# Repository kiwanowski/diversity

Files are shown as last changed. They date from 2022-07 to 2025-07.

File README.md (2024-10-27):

# diversity
an affordable DIY and open source alternative to the M8 tracker

## Limitations
The official firmware needs to be patched to work with this device.

## Support

[Please support the original M8 tracker author](https://www.patreon.com/trash80)

I won't provide support for any boards or schematics other than the ones provided in the repository.

I do not take reponsibility for any damage done. Please be sure that you understand what you are doing.

Creative Commons cc-by-sa 4.0 license.

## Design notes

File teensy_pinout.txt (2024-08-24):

0
1 - midi out
2 - LCD DC
3 - LCD RESET
4 - SD detect
5 - MCP23008 INT
6 - LCD BACKLIGHT
7 - PCM5102a DIN
8 - PCM1808 DOUT
9 - INT touch
10 - LCD CS
11 - LCD MOSI
12 - LCD MISO

13 - LCD SCK
14 - battery charger CHRG
15 - battery charger POWER ON
16 - MCP23008 SCL
17 - MCP23008 SDA
18 - audio i2s
19 - audio i2s
20 - PCM5102a LCK
21 - PCM5102a BCK
22 - Battery level input
23 - PCM5102a SCK

24 - power button
25
26 - headphones detect
27
28 - midi in
29
30 - speakers control
31
32
33

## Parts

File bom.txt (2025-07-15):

M8 board:

Teensy micromod
U1, U2, U3, U4, U5, U6, U7, U8 - Kailh Choc low profile switch https://www.aliexpress.com/item/1005006626760418.html
U1, U2, U3, U4, U5, U6, U7, U8 - Kailh Choc low profile keycap https://www.aliexpress.com/item/1005005792485443.html
J8 - 3.2 inch ILI9341 IPS LCD https://www.aliexpress.com/item/1005007253437576.html
TP4056 charger module
PCM5102A DAC module https://www.aliexpress.com/item/4000397296348.html
CS5343 ADC https://www.aliexpress.com/item/1005006998764471.html
J9 - micro SD socket https://www.aliexpress.com/item/32802051702.html
IC3 - MCP23008-E/SO
Switch SKHHLUA010 https://pl.aliexpress.com/item/1005004288237245.html
IC1 - 6N138
J3, J4, J11, J13 - headphone jack https://www.aliexpress.com/item/32439357849.html
507070 3000mah battery
Usb-C socket https://pl.aliexpress.com/item/1005006257173539.html
Switch TS-1286VE-2 https://pl.aliexpress.com/item/1005002844865456.html
LT1963AES8-3.3
M.2 socket, E key H=4.2 https://pl.aliexpress.com/item/4001262336295.html

R1, R2 2k2 ohm 0805
R5 220 ohm 0805
R3, R6, R17, R18, R19, R20 33 ohm 0805
R7 10 ohm 0805
R8 470 ohm 0805
R9 1k ohm 0805
R12, R13, R14 100k ohm 0805
R21 10k ohm 0805
R4, R10, R11, R22, R23, R24 5k1 ohm 0805
C1, C2, C5 10uF 0805
C3, C4, C6, C8, C12, C13, C22 100nF 0805
C11, C14, C15, C16, C25 1uF 0805
C7, C17 180pF 0805
D3 1N4148 SMD

Case:

4x Threaded Insert M2.5 4mm https://www.aliexpress.com/item/1005004535859664.html
4x Screw M2.5 14mm https://www.aliexpress.com/item/1005007244737272.html

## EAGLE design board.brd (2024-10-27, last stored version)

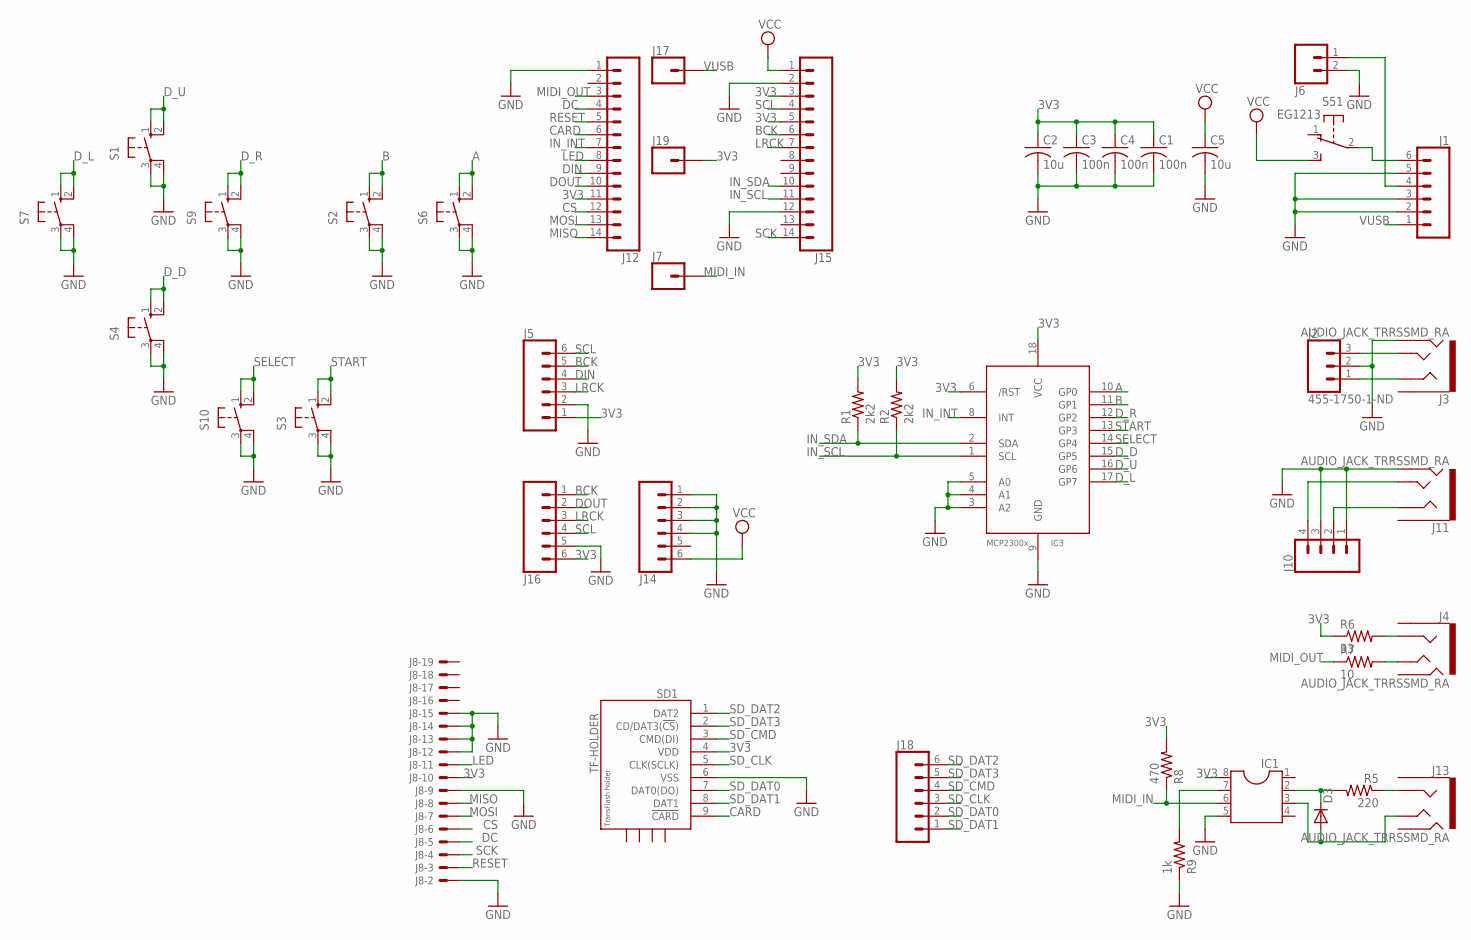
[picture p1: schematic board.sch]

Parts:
C1, C3, C4: 100n; C0805
C2, C5: 10u; C0805
D3: DIODE-MINIMELF; MINIMELF
IC1: DIL8; DIL08
IC3: MCP23008/SO; SO18W
J1, J5, J14, J16, J18: CONN_06SILK_FEMALE_PTH; 1X06
J2: 455-1750-1-ND; 1X03
J3, J4, J11, J13: AUDIO_JACK_TRRSSMD_RA; AUDIO_JACK_3.5MM_TRRS_SMD_RA
J6: CONN_02; 1X02
J7, J17, J19: CONN_01; 1X01
J8: XF2E-2015-1
J10: CONN_04; 1X04
J12, J15: CONN_14; 1X14
R1, R2: 2k2; R0805
R5: 220; R0805
R6: 33; R0805
R7: 10; R0805
R8: 470; R0805
R9: 1k; R0805
S1, S2, S3, S4, S6, S7, S9, S10: 10-XX; B3F-10XX
S5: EG1213
SD1: TF-HOLDER; TF-PULL

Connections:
3V3: C1.1, C2.1, C3.1, C4.1, IC1.8, IC3.6 (/RST), IC3.18 (VCC), J5.1, J8.10, J12.11, J15.3, J15.5, J16.6, J19.1, R1.2, R2.2, R6.1, R8.2, SD1.4 (VDD)
A: IC3.10 (GP0), S6.1 (S), S6.2 (S1)
B: IC3.11 (GP1), S2.1 (S), S2.2 (S1)
BCK: J5.5, J15.6, J16.1
CARD: J12.6, SD1.9 (!CARD)
CS: J8.6, J12.12
DC: J8.5, J12.4
DIN: J5.4, J12.9
DOUT: J12.10, J16.2
D_D: IC3.15 (GP5), S4.1 (S), S4.2 (S1)
D_L: IC3.17 (GP7), S7.1 (S), S7.2 (S1)
D_R: IC3.12 (GP2), S9.1 (S), S9.2 (S1)
D_U: IC3.16 (GP6), S1.1 (S), S1.2 (S1)
GND: C1.2, C2.2, C3.2, C4.2, C5.2, IC1.5, IC3.3 (A2), IC3.4 (A1), IC3.5 (A0), IC3.9 (GND), J1.2, J1.3, J1.5, J2.2, J3.RING2, J5.2, J6.2, J8.2, J8.9, J8.12, J8.13, J8.14, J8.15, J10.1, J10.3, J11.RING2, J12.1, J14.1, J14.2, J14.3, J14.4, J15.2, J15.12, J16.5, R9.1, S1.3, S1.4 (P1), S2.3, S2.4 (P1), S3.3, S3.4 (P1), S4.3, S4.4 (P1), S6.3, S6.4 (P1), S7.3, S7.4 (P1), S9.3, S9.4 (P1), S10.3, S10.4 (P1), SD1.6 (VSS)
IN_INT: IC3.8 (INT), J12.7
IN_SCL: IC3.1 (SCL), J15.11, R2.1
IN_SDA: IC3.2 (SDA), J15.10, R1.1
LED: J8.11, J12.8
LRCK: J5.3, J15.7, J16.3
MIDI_IN: IC1.6, J7.1, R8.1
MIDI_OUT: J12.3, R7.1
MISO: J8.8, J12.14
MOSI: J8.7, J12.13
unnamed: J2.3, J3.TIP
unnamed: J2.1, J3.RING1
unnamed: J10.4, J11.TIP
unnamed: J10.2, J11.RING1
unnamed: J1.4, J6.1
unnamed: J4.RING1, R6.2
unnamed: J4.TIP, R7.2
unnamed: J13.RING1, R5.1
unnamed: D3.C, IC1.2, R5.2
unnamed: D3.A, IC1.3, J13.TIP
unnamed: IC1.7, R9.2
unnamed: J1.6, S5.2
RESET: J8.3, J12.5
SCK: J8.4, J15.14
SCL: J5.6, J15.4, J16.4
SD_CLK: J18.3, SD1.5 (CLK(SCLK))
SD_CMD: J18.4, SD1.3 (CMD(DI))
SD_DAT0: J18.2, SD1.7 (DAT0(DO))
SD_DAT1: J18.1, SD1.8 (DAT1)
SD_DAT2: J18.6, SD1.1 (DAT2)
SD_DAT3: J18.5, SD1.2 (CD/DAT3(!CS!))
SELECT: IC3.14 (GP4), S10.1 (S), S10.2 (S1)
START: IC3.13 (GP3), S3.1 (S), S3.2 (S1)
VCC: C5.1, J14.6, J15.1, S5.3 (S)
VUSB: J1.1, J17.1

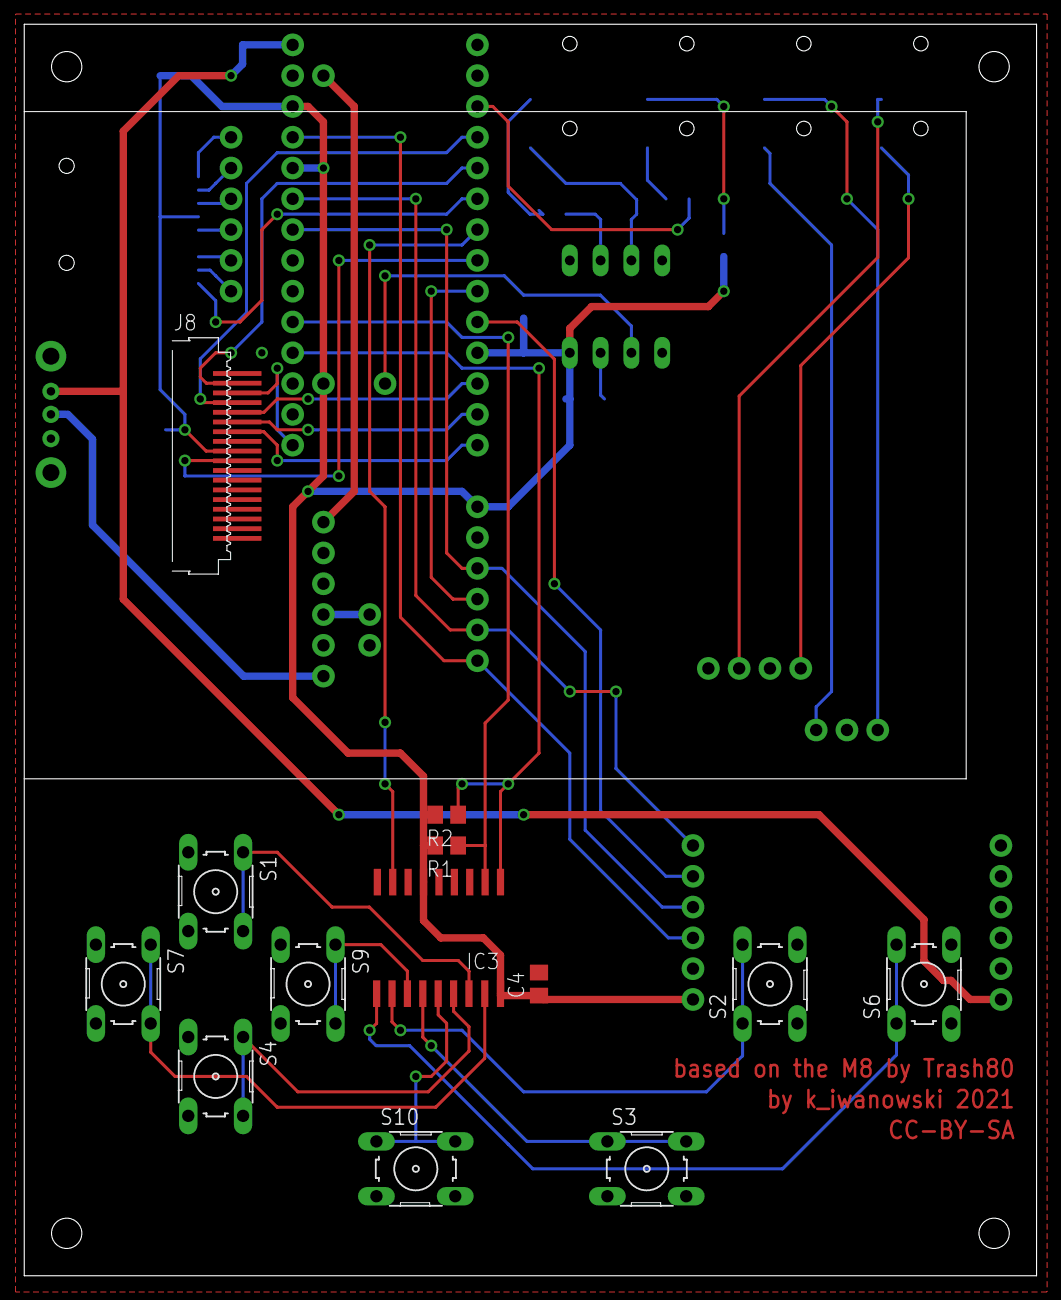
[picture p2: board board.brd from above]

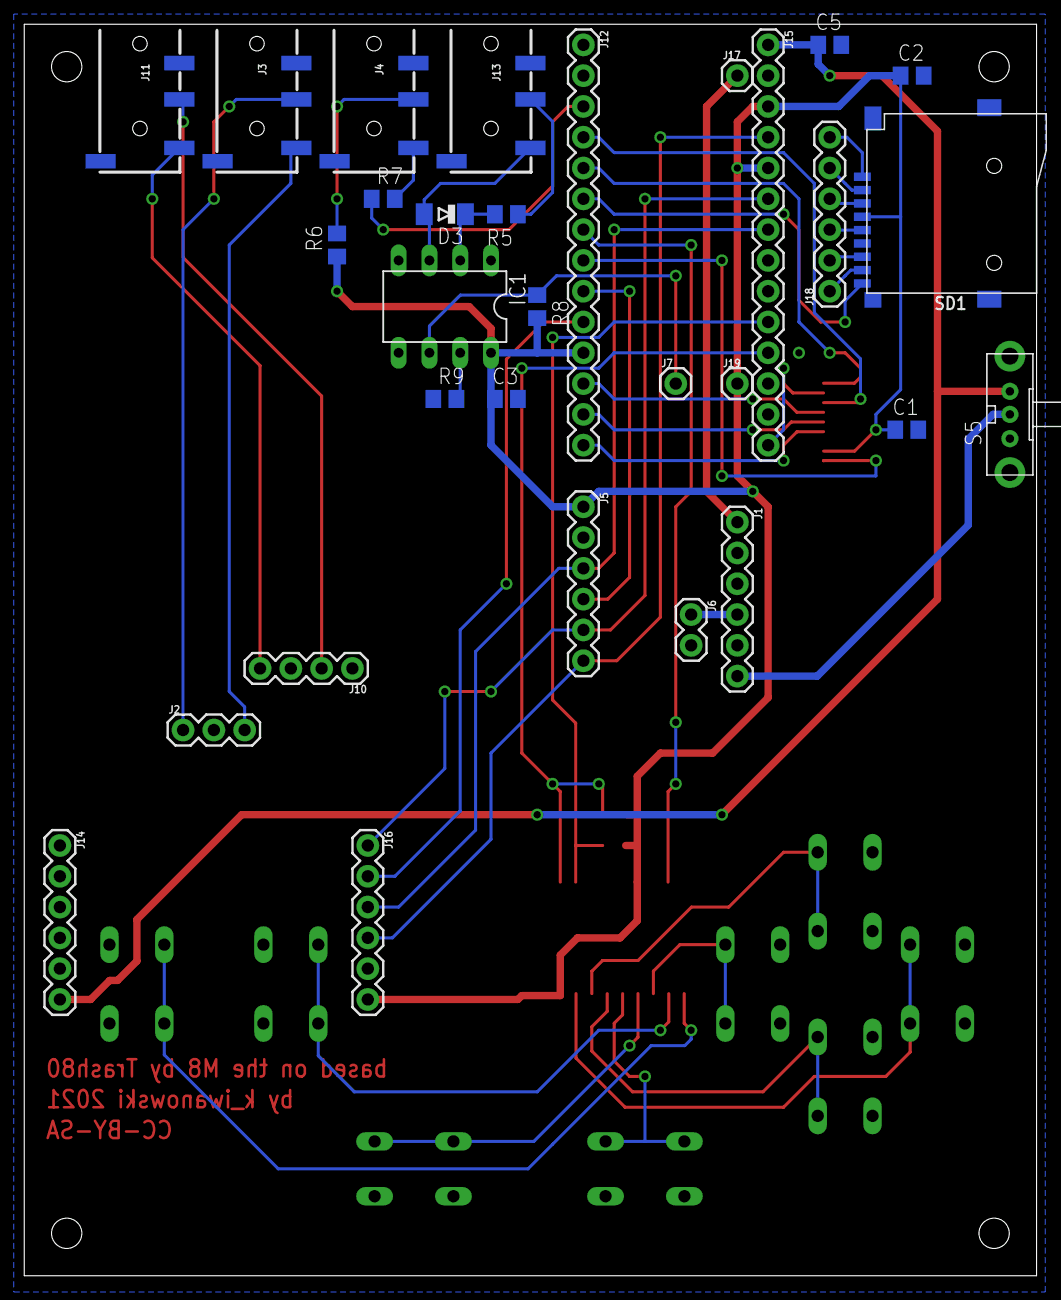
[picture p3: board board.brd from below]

Board: 2 copper layers, 83.5 x 103.2 mm, 43 parts (30 on the bottom side), 48 nets.

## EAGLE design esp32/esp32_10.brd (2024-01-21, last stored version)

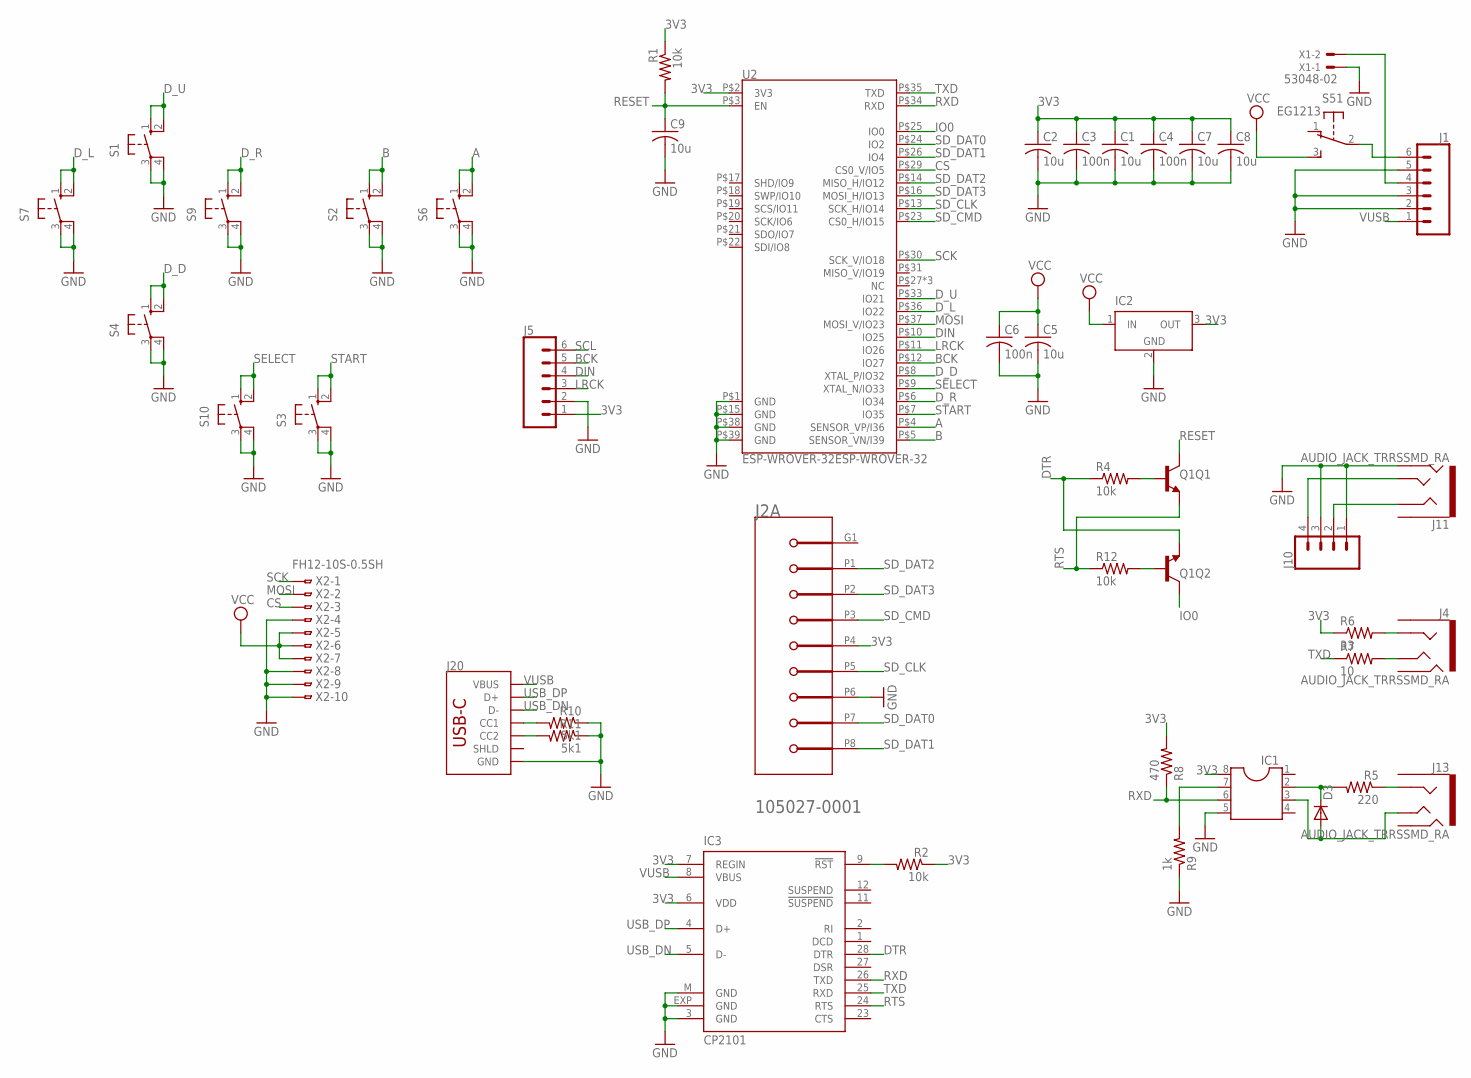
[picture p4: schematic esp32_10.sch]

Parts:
C1, C2, C5, C7, C8, C9: 10u; C0805
C3, C4, C6: 100n; C0805
D3: DIODE-MINIMELF; MINIMELF
IC1: DIL8; DIL08
IC2: LT1129CST5; SOT223
IC3: CP2101; MLP28
J1, J5: CONN_06SILK_FEMALE_PTH; 1X06
J2: MOLEX_INC_105027-0001MOLEX_INC_105027-0001_0_0; MOLEX_INC_105027-0001_0
J4, J11, J13: AUDIO_JACK_TRRSSMD_RA; AUDIO_JACK_3.5MM_TRRS_SMD_RA
J10: CONN_04; 1X04
J20: USB_C_2-LAYER_PADS; USB-C-16P-2LAYER-PADS
Q1: TRANS_NPN_DUAL-MBT3904DW1T1; SC70-6
R1, R2, R4, R12: 10k; R0805
R5: 220; R0805
R6: 33; R0805
R7: 10; R0805
R8: 470; R0805
R9: 1k; R0805
R10, R11: 5k1; R0805
S1, S2, S3, S4, S6, S7, S9, S10: 10-XX; B3F-10XX
S5: EG1213
U2: ESP-WROVER-32ESP-WROVER-32; ESP-WROVER-32
X1: 53048-02
X2: FH12-10S-0.5SH

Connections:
3V3: C1.1, C2.1, C3.1, C4.1, C7.1, C8.1, IC1.8, IC2.3 (OUT), IC3.6 (VDD), IC3.7 (REGIN), J2.P4 (VDD), J5.1, R1.1, R2.1, R6.1, R8.2, U2.P$2 (3V3)
A: S6.1 (S), S6.2 (S1), U2.P$4 (SENSOR_VP/I36)
B: S2.1 (S), S2.2 (S1), U2.P$5 (SENSOR_VN/I39)
BCK: J5.5, U2.P$12 (IO27)
CS: U2.P$29 (CS0_V/IO5), X2.3
DIN: J5.4, U2.P$10 (IO25)
DTR: IC3.28 (DTR), Q1.1 (E), R4.1
D_D: S4.1 (S), S4.2 (S1), U2.P$8 (XTAL_P/IO32)
D_L: S7.1 (S), S7.2 (S1), U2.P$36 (IO22)
D_R: S9.1 (S), S9.2 (S1), U2.P$6 (IO34)
D_U: S1.1 (S), S1.2 (S1), U2.P$33 (IO21)
GND: C1.2, C2.2, C3.2, C4.2, C5.2, C6.2, C7.2, C8.2, C9.2, IC1.5, IC2.2 (GND), IC2.4 (GND), IC3.3 (GND), IC3.EXP (GND), IC3.M (GND), J1.2, J1.3, J1.5, J2.P6 (VSS), J5.2, J10.1, J10.3, J11.RING2, J20.GND, J20.GND2 (GND), R9.1, R10.1, R11.1, S1.3, S1.4 (P1), S2.3, S2.4 (P1), S3.3, S3.4 (P1), S4.3, S4.4 (P1), S6.3, S6.4 (P1), S7.3, S7.4 (P1), S9.3, S9.4 (P1), S10.3, S10.4 (P1), U2.P$1 (GND), U2.P$15 (GND), U2.P$38 (GND), U2.P$39 (GND), X1.1, X2.4, X2.8, X2.9, X2.10
IO0: Q1.6 (C), U2.P$25 (IO0)
LRCK: J5.3, U2.P$11 (IO26)
MOSI: U2.P$37 (MOSI_V/IO23), X2.2
unnamed: J10.4, J11.TIP
unnamed: J10.2, J11.RING1
unnamed: J1.4, X1.2
unnamed: Q1.2 (B), R12.2
unnamed: J20.A5 (CC1), R10.2
unnamed: J20.B5 (CC2), R11.2
unnamed: Q1.5 (B), R4.2
unnamed: J4.RING1, R6.2
unnamed: J4.TIP, R7.2
unnamed: J13.RING1, R5.1
unnamed: D3.C, IC1.2, R5.2
unnamed: D3.A, IC1.3, J13.TIP
unnamed: IC1.7, R9.2
unnamed: J1.6, S5.2
unnamed: IC3.9 (!RST), R2.2
RESET: C9.1, Q1.3 (C), R1.2, U2.P$3 (EN)
RTS: IC3.24 (RTS), Q1.4 (E), R12.1
RXD: IC1.6, IC3.26 (TXD), R8.1, U2.P$34 (RXD)
SCK: U2.P$30 (SCK_V/IO18), X2.1
SCL: J5.6
SD_CLK: J2.P5 (CLK), U2.P$13 (SCK_H/IO14)
SD_CMD: J2.P3 (CMD), U2.P$23 (CS0_H/IO15)
SD_DAT0: J2.P7 (DAT0), U2.P$24 (IO2)
SD_DAT1: J2.P8 (DAT1), U2.P$26 (IO4)
SD_DAT2: J2.P1 (DAT2), U2.P$14 (MISO_H/IO12)
SD_DAT3: J2.P2 (CD/DAT3), U2.P$16 (MOSI_H/IO13)
SELECT: S10.1 (S), S10.2 (S1), U2.P$9 (XTAL_N/IO33)
START: S3.1 (S), S3.2 (S1), U2.P$7 (IO35)
TXD: IC3.25 (RXD), R7.1, U2.P$35 (TXD)
USB_DN: IC3.5 (D-), J20.A7 (D-), J20.B7 (D-)
USB_DP: IC3.4 (D+), J20.A6 (D+), J20.B6 (D+)
VCC: C5.1, C6.1, IC2.1 (IN), S5.3 (S), X2.5, X2.6, X2.7
VUSB: IC3.8 (VBUS), J1.1, J20.VBUS1 (VBUS), J20.VBUS2 (VBUS)

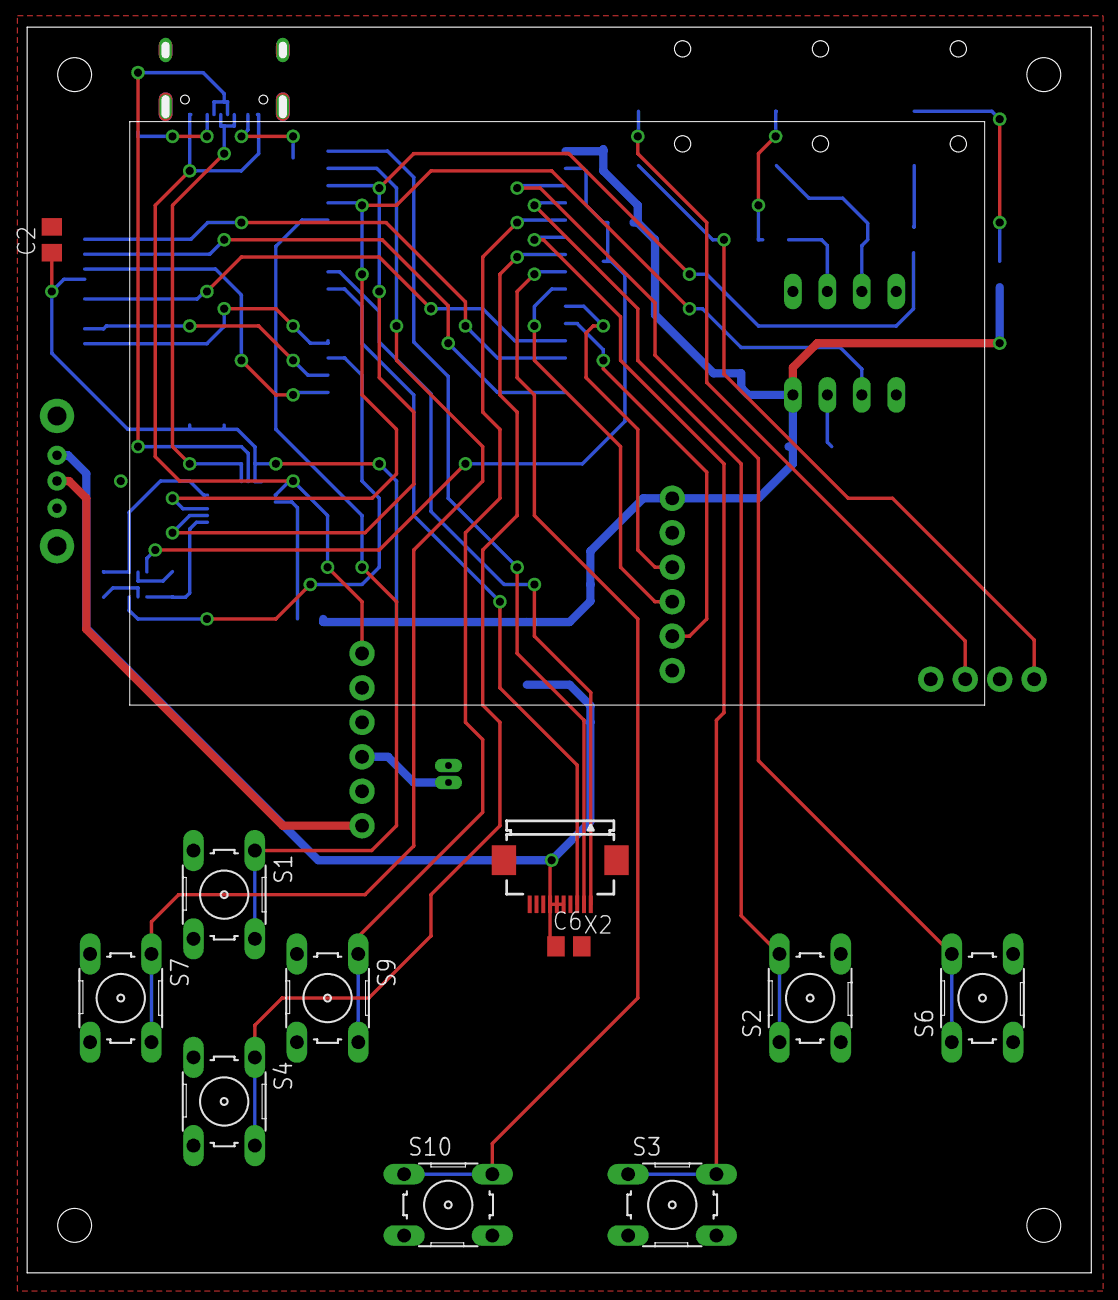
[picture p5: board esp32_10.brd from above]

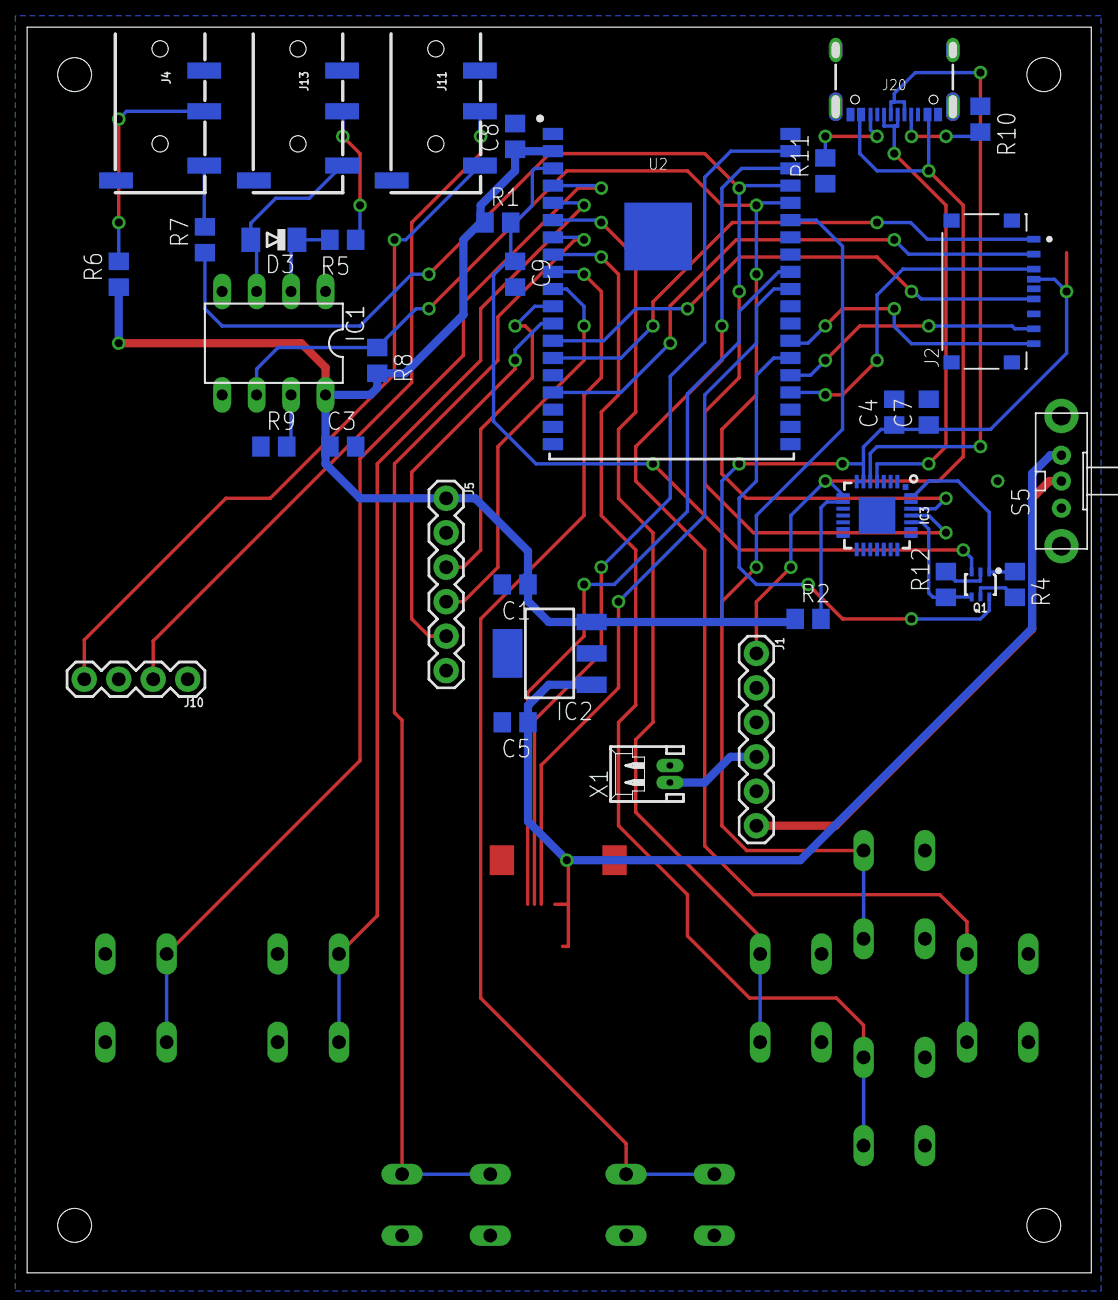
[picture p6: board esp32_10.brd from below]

Board: 2 copper layers, 78.4 x 91.8 mm, 45 parts (34 on the bottom side), 47 nets.

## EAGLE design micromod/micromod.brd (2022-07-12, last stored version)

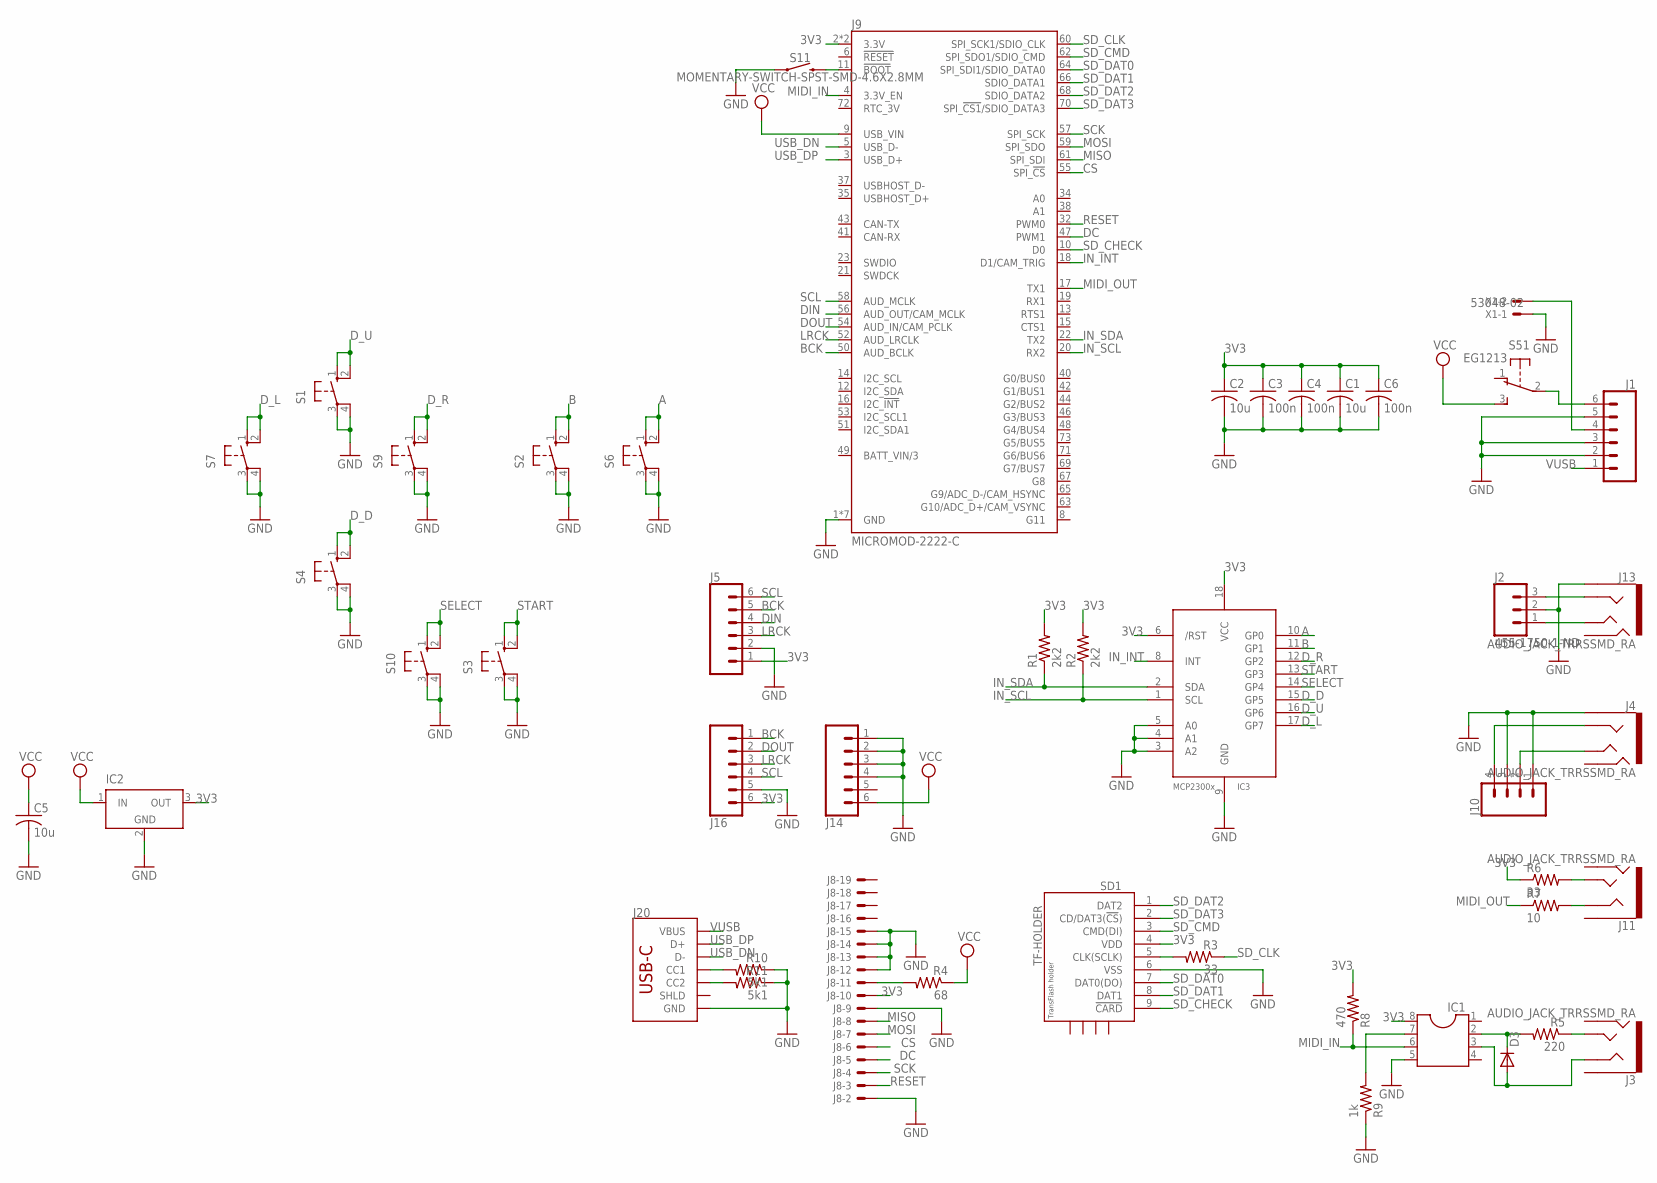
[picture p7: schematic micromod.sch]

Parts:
C1, C2, C5: 10u; C0805
C3, C4, C6: 100n; C0805
D3: DIODE-MINIMELF; MINIMELF
IC1: DIL8; DIL08
IC2: LT1129CST5; SOT223
IC3: MCP23008/SO; SO18W
J1, J5, J14, J16: CONN_06SILK_FEMALE_PTH; 1X06
J2: 455-1750-1-ND; 1X03
J3, J4, J11, J13: AUDIO_JACK_TRRSSMD_RA; AUDIO_JACK_3.5MM_TRRS_SMD_RA
J8: XF2E-2015-1
J9: MICROMOD-2222-C; M.2-CONNECTOR-E
J10: CONN_04; 1X04
J20: USB_C_2-LAYER_PADS; USB-C-16P-2LAYER-PADS
R1, R2: 2k2; R0805
R3, R6: 33; R0805
R4: 68; R0805
R5: 220; R0805
R7: 10; R0805
R8: 470; R0805
R9: 1k; R0805
R10, R11: 5k1; R0805
S1, S2, S3, S4, S6, S7, S9, S10: 10-XX; B3F-10XX
S5: EG1213
S11: MOMENTARY-SWITCH-SPST-SMD-4.6X2.8MM; TACTILE_SWITCH_SMD_4.6X2.8MM
SD1: TF-HOLDER; TF-PULL
X1: 53048-02

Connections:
3V3: C1.1, C2.1, C3.1, C4.1, C6.1, IC1.8, IC2.3 (OUT), IC3.6 (/RST), IC3.18 (VCC), J5.1, J8.10, J9.2 (3.3V), J9.74 (3.3V), J16.6, R1.2, R2.2, R6.1, R8.2, SD1.4 (VDD)
A: IC3.10 (GP0), S6.1 (S), S6.2 (S1)
B: IC3.11 (GP1), S2.1 (S), S2.2 (S1)
BCK: J5.5, J9.50 (AUD_BCLK), J16.1
CS: J8.6, J9.55 (SPI_!CS!)
DC: J8.5, J9.47 (PWM1)
DIN: J5.4, J9.56 (AUD_OUT/CAM_MCLK)
DOUT: J9.54 (AUD_IN/CAM_PCLK), J16.2
D_D: IC3.15 (GP5), S4.1 (S), S4.2 (S1)
D_L: IC3.17 (GP7), S7.1 (S), S7.2 (S1)
D_R: IC3.12 (GP2), S9.1 (S), S9.2 (S1)
D_U: IC3.16 (GP6), S1.1 (S), S1.2 (S1)
GND: C1.2, C2.2, C3.2, C4.2, C5.2, C6.2, IC1.5, IC2.2 (GND), IC2.4 (GND), IC3.3 (A2), IC3.4 (A1), IC3.5 (A0), IC3.9 (GND), J1.2, J1.3, J1.5, J2.2, J4.EARTH, J5.2, J8.2, J8.9, J8.12, J8.13, J8.14, J8.15, J9.1 (GND), J9.7 (GND), J9.33 (GND), J9.36 (GND), J9.39 (GND), J9.45 (GND), J9.75 (GND), J10.1, J10.3, J13.EARTH, J14.1, J14.2, J14.3, J14.4, J16.5, J20.GND, J20.GND2 (GND), R9.1, R10.1, R11.1, S1.3, S1.4 (P1), S2.3, S2.4 (P1), S3.3, S3.4 (P1), S4.3, S4.4 (P1), S6.3, S6.4 (P1), S7.3, S7.4 (P1), S9.3, S9.4 (P1), S10.3, S10.4 (P1), S11.1, S11.2 (1), SD1.6 (VSS), X1.1
IN_INT: IC3.8 (INT), J9.18 (D1/CAM_TRIG)
IN_SCL: IC3.1 (SCL), J9.20 (RX2), R2.1
IN_SDA: IC3.2 (SDA), J9.22 (TX2), R1.1
LRCK: J5.3, J9.52 (AUD_LRCLK), J16.3
MIDI_IN: IC1.6, J9.4 (3.3V_EN), R8.1
MIDI_OUT: J9.17 (TX1), R7.1
MISO: J8.8, J9.61 (SPI_SDI)
MOSI: J8.7, J9.59 (SPI_SDO)
unnamed: J8.11, R4.2
unnamed: J2.3, J13.RING1
unnamed: J2.1, J13.TIP
unnamed: J4.RING1, J10.4
unnamed: J4.TIP, J10.2
unnamed: J1.4, X1.2
unnamed: R3.2, SD1.5 (CLK(SCLK))
unnamed: J20.A5 (CC1), R10.2
unnamed: J20.B5 (CC2), R11.2
unnamed: J9.11 (!BOOT!), S11.3 (2), S11.4 (2)
unnamed: J3.TIP, R5.1
unnamed: J11.TIP, R6.2
unnamed: J11.RING1, R7.2
unnamed: D3.C, IC1.2, R5.2
unnamed: D3.A, IC1.3, J3.RING1
unnamed: IC1.7, R9.2
unnamed: J1.6, S5.2
RESET: J8.3, J9.32 (PWM0)
SCK: J8.4, J9.57 (SPI_SCK)
SCL: J5.6, J9.58 (AUD_MCLK), J16.4
SD_CHECK: J9.10 (D0), SD1.9 (!CARD)
SD_CLK: J9.60 (SPI_SCK1/SDIO_CLK), R3.1
SD_CMD: J9.62 (SPI_SDO1/SDIO_CMD), SD1.3 (CMD(DI))
SD_DAT0: J9.64 (SPI_SDI1/SDIO_DATA0), SD1.7 (DAT0(DO))
SD_DAT1: J9.66 (SDIO_DATA1), SD1.8 (DAT1)
SD_DAT2: J9.68 (SDIO_DATA2), SD1.1 (DAT2)
SD_DAT3: J9.70 (SPI_!CS1!/SDIO_DATA3), SD1.2 (CD/DAT3(!CS!))
SELECT: IC3.14 (GP4), S10.1 (S), S10.2 (S1)
START: IC3.13 (GP3), S3.1 (S), S3.2 (S1)
USB_DN: J9.5 (USB_D-), J20.A7 (D-), J20.B7 (D-)
USB_DP: J9.3 (USB_D+), J20.A6 (D+), J20.B6 (D+)
VCC: C5.1, IC2.1 (IN), J9.9 (USB_VIN), J14.6, R4.1, S5.3 (S)
VUSB: J1.1, J20.VBUS1 (VBUS), J20.VBUS2 (VBUS)

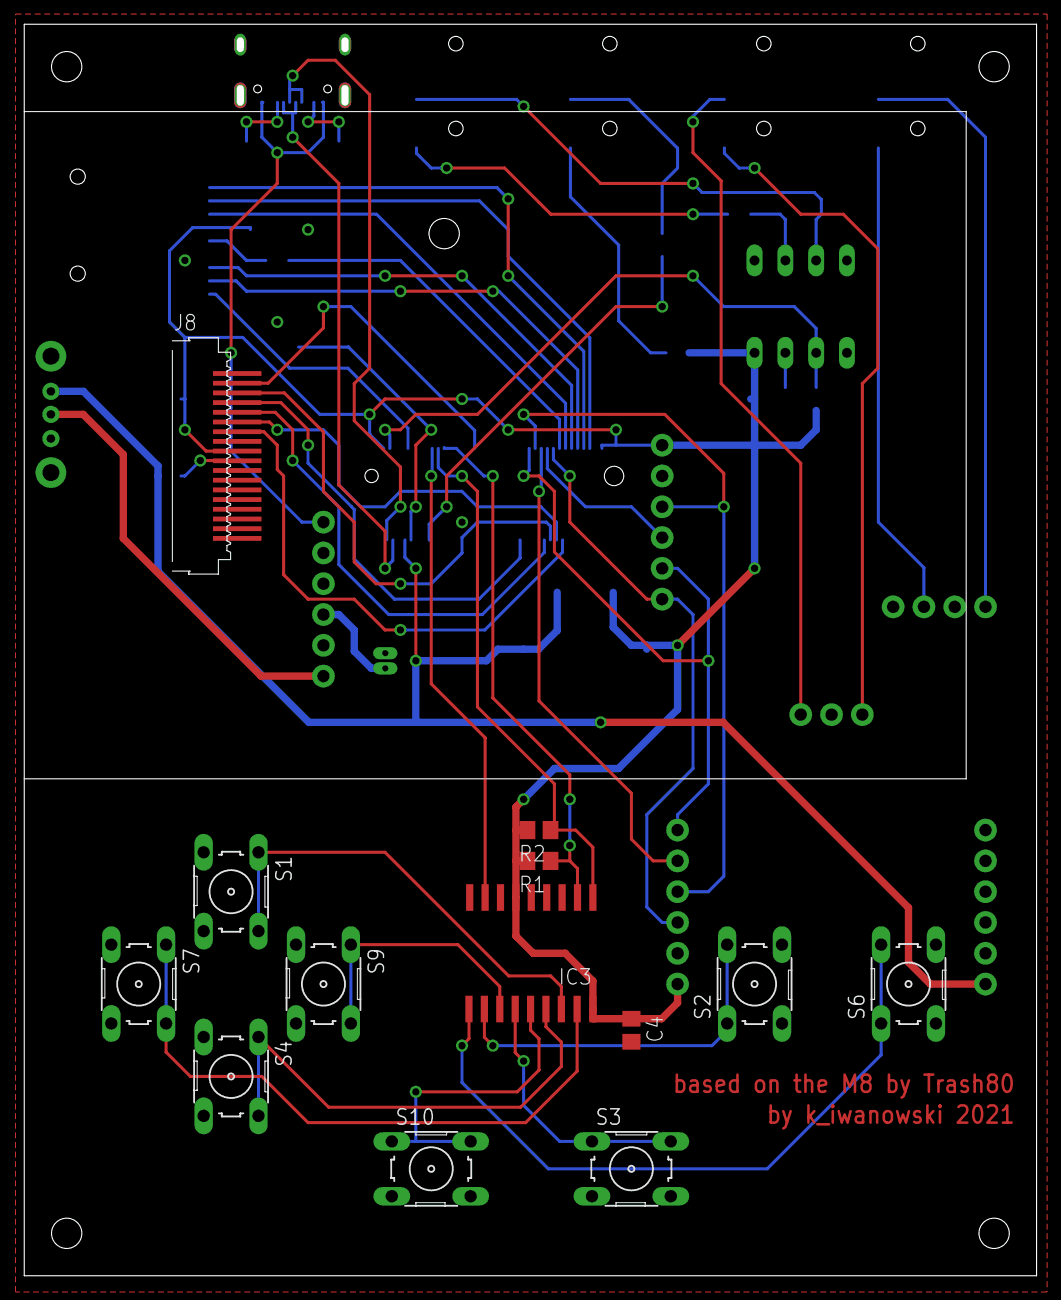
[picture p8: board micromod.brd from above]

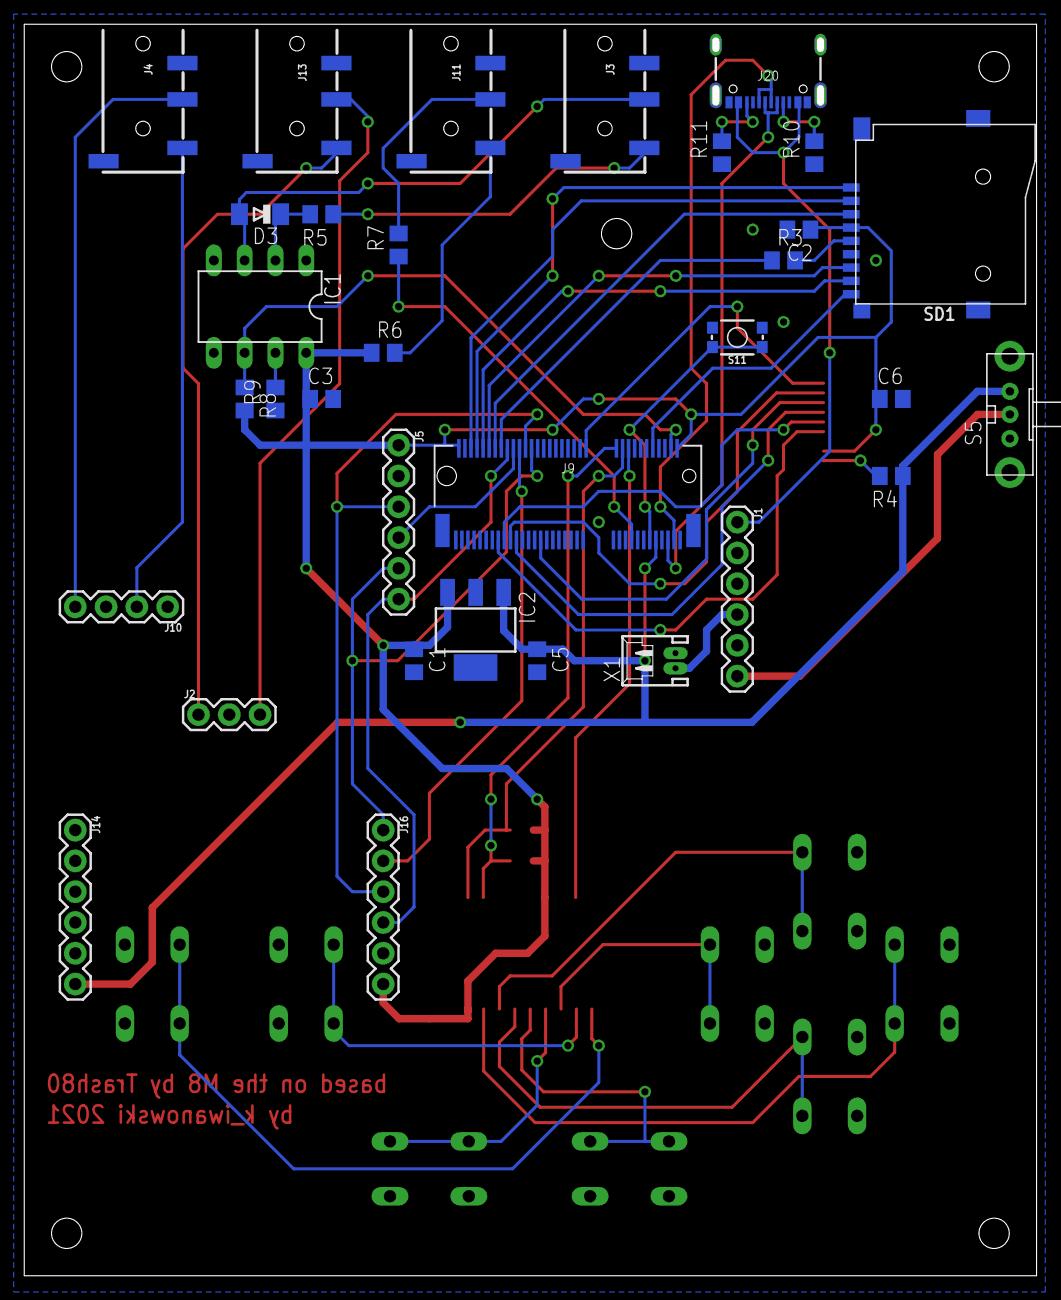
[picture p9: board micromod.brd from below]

Board: 2 copper layers, 83.5 x 103.2 mm, 46 parts (33 on the bottom side), 54 nets.

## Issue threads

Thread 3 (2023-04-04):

SD Card not present - Micromod Edition

mcb, 2023-04-04:
Hi @kiwanowski

thanks a ton for your work on this one. Unfortunately I am facing the same issue like in #2 where the SD Card is not detected and the teensy shuts off. I installed v1.3.8 for this one and had PCBs printed off your design (only had to change the FCC Connector as it wasn't available), pictures below. As per your Drawings, Pin 70 of the m2 Connector goes to Pin 2 of the SD Card Reader, which is the respective Card Detect Pin, Pin 6 of the SD goes to GND. Do you happen to know the issue or could point me into the right direction? Happy to provide a Picture of the raw PCB, but I believe the one below might help more.

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

mcb, 2023-04-04:
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

Adding the (not yet) unpopulated PCB as most of it remains hidden after adding the other components.

mcb, 2023-04-06:
Does anybody else have a similar problem? Appreciate it if someone can give me a hint to fix this.

kiwanowski, 2023-04-06:
Hey, Im sorry, but the micromod pcb is a proof of concept. There is no working fw for this board. We need to wait until the fw is open source or reverse engineered and modified for this board

mcb, 2023-04-07:
Hi @kiwanowski thats unfortunate, maybe I can send a pull request to include that info in the readme? Seems like my only options are to wait or build the alternative via teensy. Is that one confirmed to work?

mcb, 2023-04-11:
@kiwanowski Just sent the pull request. Can you please elaborate if the teensy version is confirmed to work?

kiwanowski, 2023-04-11:
Im sorry, but I cant guarantee you that the teensy version will work for you. The reasons are:
-I don't know anyone besides me that made a working clone of the m8.
-There can be errors in the board files. For example last year someone pointed out to me that there is an error in the adapter board file I uploaded.
-The build process is quite hard and its not documented.  Only half of the boards I made worked on the first try. Thats why I designed the micromod version as its super easy in comparison

mcb, 2023-04-11:
Thanks for the clarification, appreciate it!

DRCRecoveryData, 2024-09-25:
> Hi @kiwanowski
>
> thanks a ton for your work on this one. Unfortunately I am facing the same issue like in #2 where the SD Card is not detected and the teensy shuts off. I installed v1.3.8 for this one and had PCBs printed off your design (only had to change the FCC Connector as it wasn't available), pictures below. As per your Drawings, Pin 70 of the m2 Connector goes to Pin 2 of the SD Card Reader, which is the respective Card Detect Pin, Pin 6 of the SD goes to GND. Do you happen to know the issue or could point me into the right direction? Happy to provide a Picture of the raw PCB.

I have same issue when turn on teensy auto shutdown and screen show in white theme have you solved this issue?

Closed 2023-04-11.

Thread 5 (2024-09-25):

Does your new pcb fix the sdcard not detect and auto shutdown issue?

DRCRecoveryData, 2024-09-25:
Hi,
Does this run directly the v1.3.8 or via sdcard gameboy method?

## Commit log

2022-07-12 micromod version
    [micromod.brd, micromod.sch]
2022-07-15 adapter fix
    [adapter.brd, adapter.sch]
2023-06-26 tests for micromod
    added test programs for the micromod pcb
    [micromod.brd, micromod.sch]
2024-01-21 esp32 handheld
    [esp32_10.brd, esp32_10.sch]
2024-08-24 pcb fixes
    -added an option for the LCD backlight to be adjusted in the device menu
    -changed the sd card slot, now its possible to run the device without an sd card
    -changed the case filename - the case probably has to be updated due to the new sd card slot
    [board.brd, board.sch]
2024-08-24 small pcb fix
    [board.brd, board.sch]
2024-09-30 deleted unusable boards
    [esp32_10.brd, esp32_10.sch, micromod.brd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]
2024-10-27 pcb update
    [board.brd, board.sch]
2025-05-12 Removing outdated files
    [adapter.brd, adapter.sch, board.brd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]
2025-07-15 Added the new BOM file

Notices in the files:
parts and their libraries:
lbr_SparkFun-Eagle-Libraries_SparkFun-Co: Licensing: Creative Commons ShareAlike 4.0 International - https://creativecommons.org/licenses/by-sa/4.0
